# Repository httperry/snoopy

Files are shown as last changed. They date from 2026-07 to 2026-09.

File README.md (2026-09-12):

<picture>
  <source media="(prefers-color-scheme: dark)" srcset="Resources/Icons/Snoopy Exports/Snoopy-macOS-Default-1024@1x.png">
  <source media="(prefers-color-scheme: light)" srcset="Resources/Icons/Snoopy Exports/Snoopy-macOS-Dark-1024@1x.png">
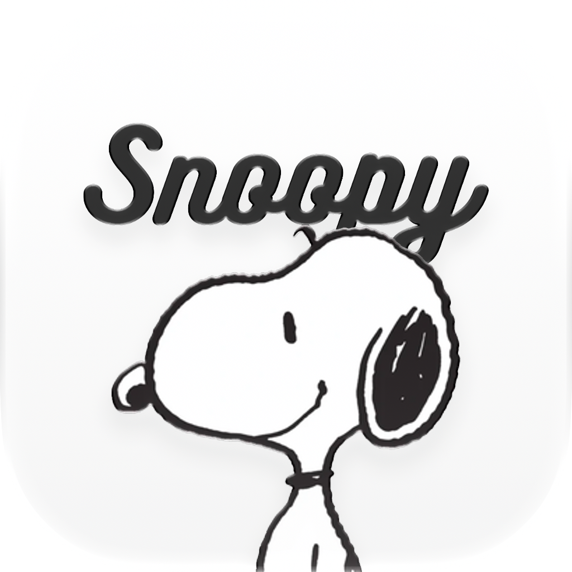
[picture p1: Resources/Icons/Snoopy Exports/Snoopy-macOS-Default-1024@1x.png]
Snoopy Icon
  
</picture>

# Snoopy





**A 3-port Ethernet switch with a built-in monitoring layer, powered by a Raspberry Pi CM4. Sits between your ISP's router and your devices, giving you real visibility and control over your home network — something most stock router software simply doesn't offer**

EasyEDA: [Snoopy](https://u.easyeda.com/join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)
To view on EasyEDA accept the invitation, then go to EasyEDA editor and see the shared project there not on OSWLab

BOM: [BOM.csv](./BOM.csv)

---

**Navigate:** [Schematics](./Schematics/README.md) · [PCB](./PCB/README.md) · [Enclosure](./Enclosure/README.md) · [BOM](./BOM.md) · [Resources](./Resources/README.md)

---

## Overview

Snoopy is a custom PCB that combines a 3-port Gigabit Ethernet switch (Realtek RTL8367S) with a Raspberry Pi CM4 as the system brain. The idea is simple: your ISP's router is a locked-down box, and there's only so much you can do with its stock software. Snoopy plugs into that setup and hands control back to you — packet inspection, traffic monitoring, custom routing rules, whatever you want to run on the CM4

The board handles its own power management, runs the CM4 over a high-density board-to-board connector, and exposes two RJ45 MagJack ports for the switch-side connections. Designed in EasyEDA

For component details, see the [BOM](./BOM.md). For schematics, head to [Schematics](./Schematics/README.md)

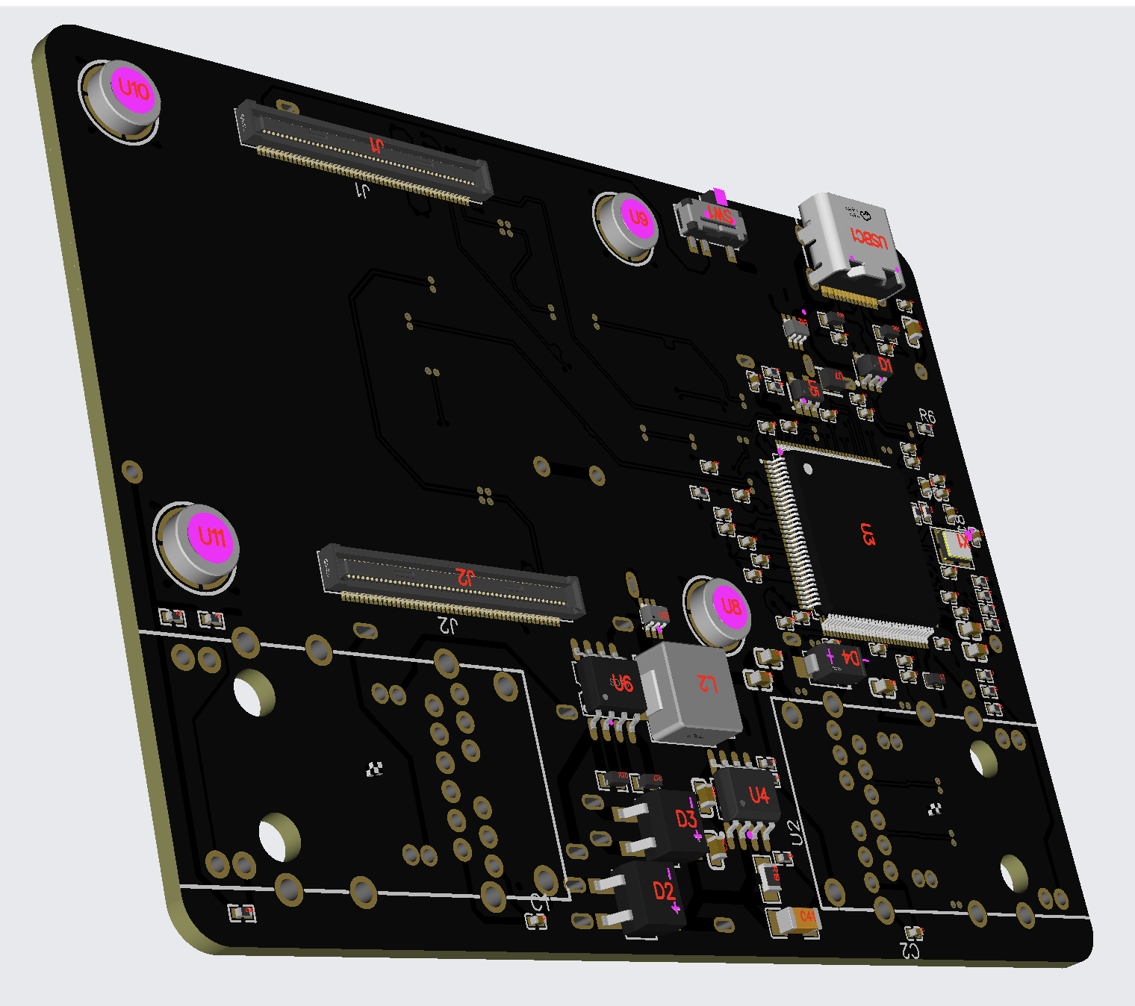
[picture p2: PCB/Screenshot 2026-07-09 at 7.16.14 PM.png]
PCB


---

## Progress

| Module | Status | Schematic |
|---|---|---|
| PWR Management |  | [View](./Schematics/PWR%20Management/README.md) |
| Ethernet Connections |  | [View](./Schematics/Ethernet%20Connections/README.md) |
| CM4 Connections |  | [View](./Schematics/CM4%20Connections/README.md) |
| PCB Layout & Routing |  | [View](./PCB/README.md) |
| Enclosure |  | [View](./Enclosure/README.md) |

---

## License

MIT — see [LICENSE](./LICENSE)

---

Hack Club &nbsp; A [Hack Club](https://hackclub.com) project, built for [Macondo](https://github.com/hackclub/macondo).

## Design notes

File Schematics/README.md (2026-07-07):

[← Back to Root](https://github.com/httperry/snoopy)

# Schematics




EasyEDA schematic sheets for Snoopy, one folder per functional module. Each folder contains the schematic as a PDF, PNG, and SVG export

---

| Module | Status | Directory |
|---|---|---|
| PWR Management |  | [PWR Management](./PWR%20Management/README.md) |
| Ethernet Connections |  | [Ethernet Connections](./Ethernet%20Connections/README.md) |
| CM4 Connections |  | [CM4 Connections](./CM4%20Connections/README.md) |

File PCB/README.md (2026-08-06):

[← Back to Root](https://github.com/httperry/snoopy)

# PCB Layout & Routing




Full board layout and routing for Snoopy — 3-port Ethernet switch with CM4. Gerbers are production-ready and exported for JLCPCB

---

PCB Preview

---

## Exports

| File | Format | Description |
|---|---|---|
| [Gerber_Snoopy_PCB_Snoopy_2026-07-09.zip](./Gerber_Snoopy_PCB_Snoopy_2026-07-09.zip) | ZIP | Gerber files for fabrication |
| [PCB_PCB_Snoopy_2026-08-06.json](./PCB_PCB_Snoopy_2026-08-06.json) | JSON | JSON PCB files |
| [PCB_PCB-Snoopy_2026-07-09.svg](./PCB_PCB-Snoopy_2026-07-09.svg) | SVG | Full board SVG export |
| [PickAndPlace_PCB_Snoopy_2026-07-09.csv](./PickAndPlace_PCB_Snoopy_2026-07-09.csv) | CSV | Pick and place file for assembly |

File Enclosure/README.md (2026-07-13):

[← Back to Root](https://github.com/httperry/snoopy)

# Enclosure




3D-printed enclosure for Snoopy, designed in Fusion 360. Split into a top and bottom shell that sandwich the PCB

---

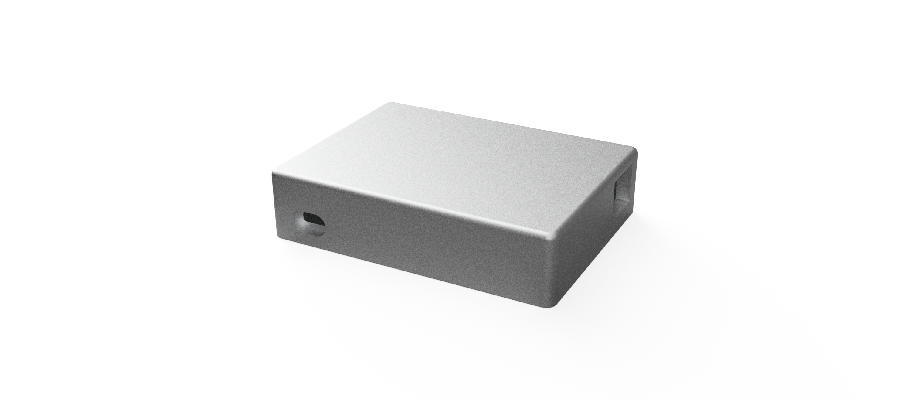
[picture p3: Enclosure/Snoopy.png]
Enclosure


---

## Exports

| File | Format | Description |
|---|---|---|
| [Snoopy.f3d](./Snoopy.f3d) | F3D | Full assembly Fusion 360 source file |
| [Snoopy.step](./Snoopy.step) | STEP | Full assembly STEP export (for slicing / import) |
| [TopShell.f3d](./TopShell.f3d) | F3D | Top shell Fusion 360 source |
| [BottomShell.step](./BottomShell.step) | STEP | Bottom shell STEP export |

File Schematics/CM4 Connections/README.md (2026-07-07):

[← Back to Root](https://github.com/httperry/snoopy)

# CM4 Connections



Covers the interface between the board and the Raspberry Pi CM4. The CM4 connects through two high-density 100-pin DF40C board-to-board connectors (J1, J2), which carry power, USB, PCIe, HDMI, and the RGMII signals that feed into the RTL8367S switch. Also includes the USB-C port for programming and a reset/boot switch

---

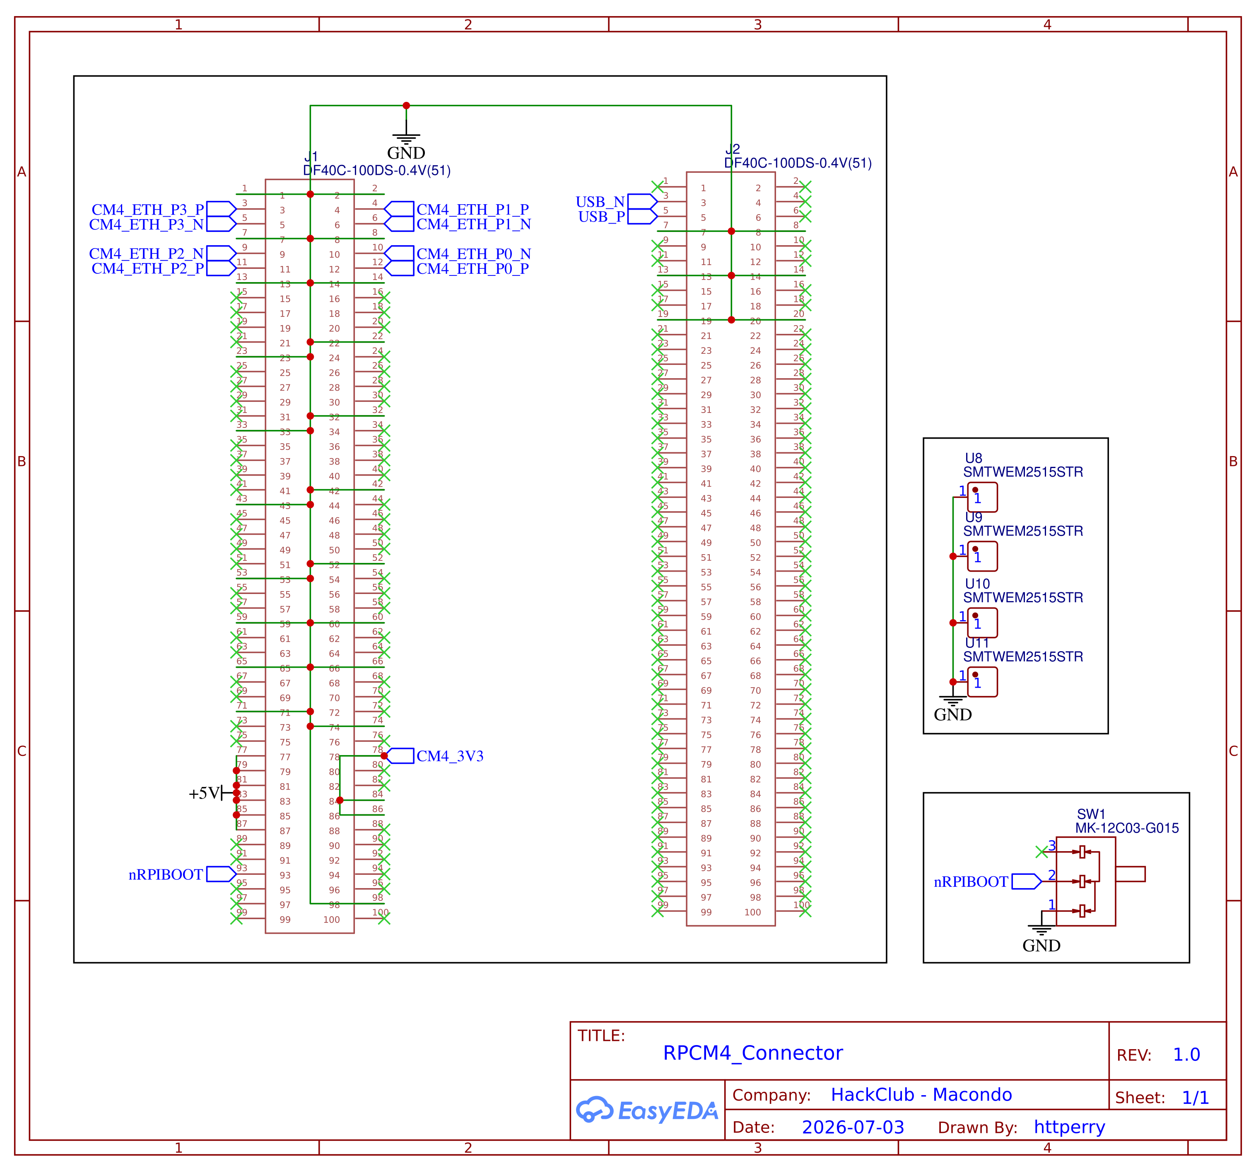
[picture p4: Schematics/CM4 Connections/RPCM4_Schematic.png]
CM4 Connections Schematic


---

## Exports

| File | Format |
|---|---|
| [RPCM4_Schematic.pdf](./RPCM4_Schematic.pdf) | PDF |
| [RPCM4_Schematic.png](./RPCM4_Schematic.png) | PNG |
| [RPCM4_Connector_2026-07-06.svg](./RPCM4_Connector_2026-07-06.svg) | SVG |

---

## Key Components

| Component | Part | Function |
|---|---|---|
| J1, J2 | DF40C-100DS-0.4V(51) | CM4 board-to-board connectors (100-pin, 0.4mm pitch) |
| USBC1 | TYPE-C-31-M-12 | USB-C port for CM4 programming |
| SW1 | MK-12C03-G015 | Power / boot select switch |
| U12, U13 | LM66100DCKR | Ideal diode for power rail protection |
| U7 | FTC201610S2R2MBCA | 2.2µH inductor for CM4 supply filtering |

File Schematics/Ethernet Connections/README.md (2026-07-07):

[← Back to Root](https://github.com/httperry/snoopy)

# Ethernet Connections



The switch fabric and physical layer connections. The RTL8367S acts as the 3-port GbE switch IC, with two ports broken out to integrated MagJack connectors (JT7-1119NL) and the third port connecting internally to the CM4's RGMII interface. Pulse transformers (SMTWEM2515STR) handle the magnetics for each port, and a 25MHz crystal provides the reference clock

---

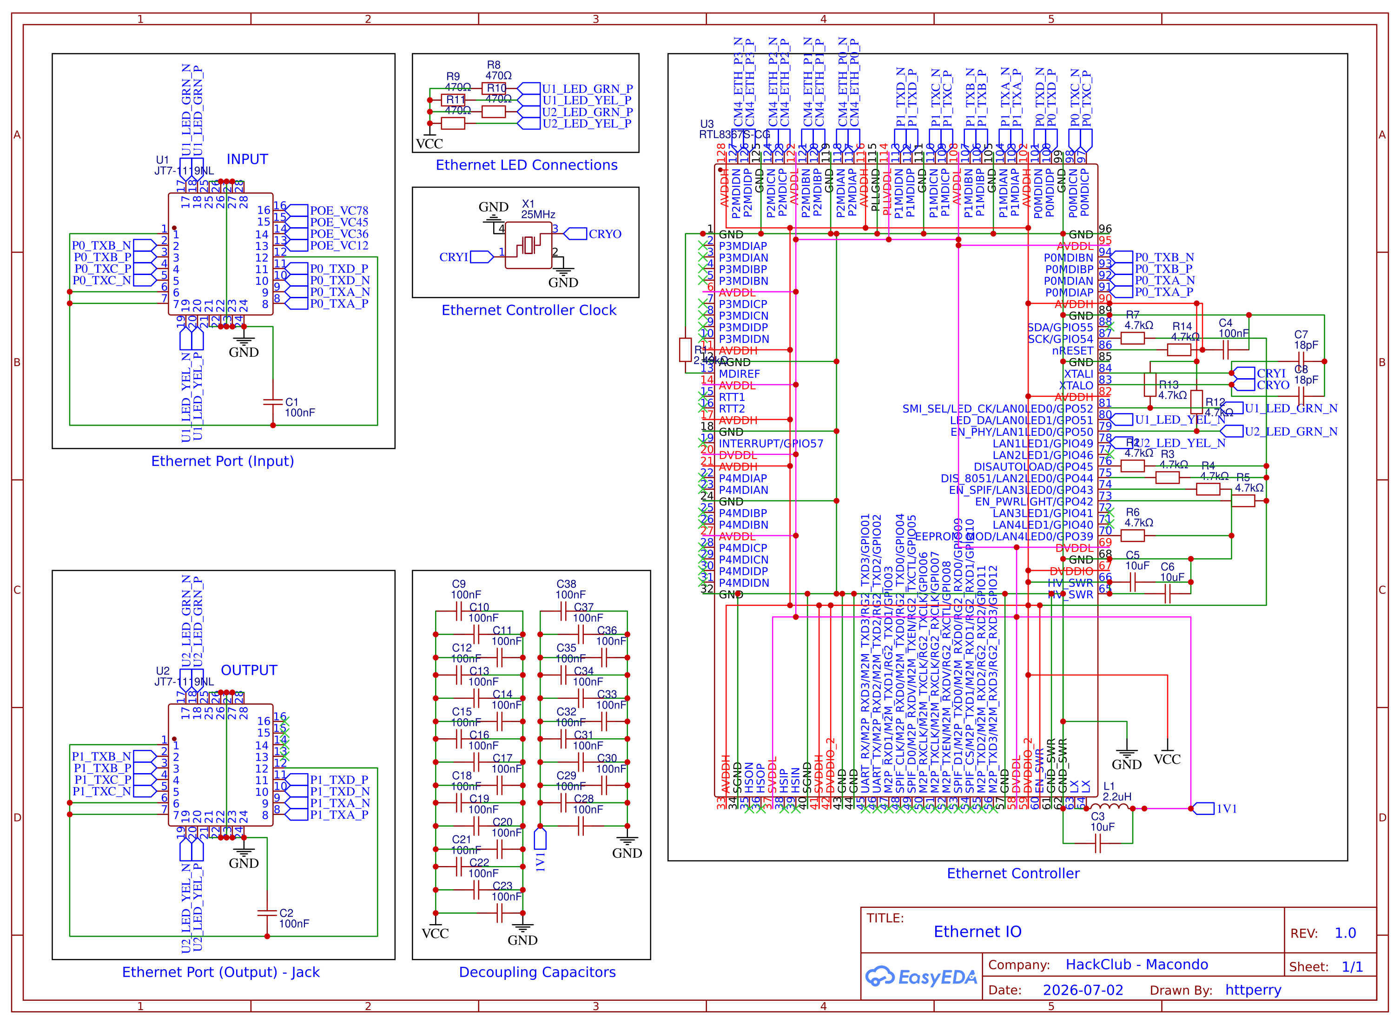
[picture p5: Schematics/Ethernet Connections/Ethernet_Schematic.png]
Ethernet Connections Schematic


---

## Exports

| File | Format |
|---|---|
| [Ethernet_Schematic.pdf](./Ethernet_Schematic.pdf) | PDF |
| [Ethernet_Schematic.png](./Ethernet_Schematic.png) | PNG |
| [Ethernet_IO_2026-07-06.svg](./Ethernet_IO_2026-07-06.svg) | SVG |

---

## Key Components

| Component | Part | Function |
|---|---|---|
| U3 | RTL8367S-CG | 3-port Gigabit Ethernet switch IC |
| U1, U2 | JT7-1119NL | Integrated MagJack (GbE RJ45 with magnetics) |
| U8–U11 | SMTWEM2515STR | Ethernet pulse transformers |
| X1 | TAXM25M4RLBCCT2T | 25MHz reference crystal |
| D1 | USBLC6-2SC6 | ESD protection |

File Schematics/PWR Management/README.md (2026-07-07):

[← Back to Root](https://github.com/httperry/snoopy)

# PWR Management



Handles all power rails on the board. Takes input via USB-C or PoE, steps it down to the voltages needed by the CM4, the RTL8367S switch, and other ICs. Uses two buck converters (TPS54360 and SY8089) alongside a PoE PD controller (TPS2378) and a pair of LM66100 ideal diode controllers for input source arbitration

---

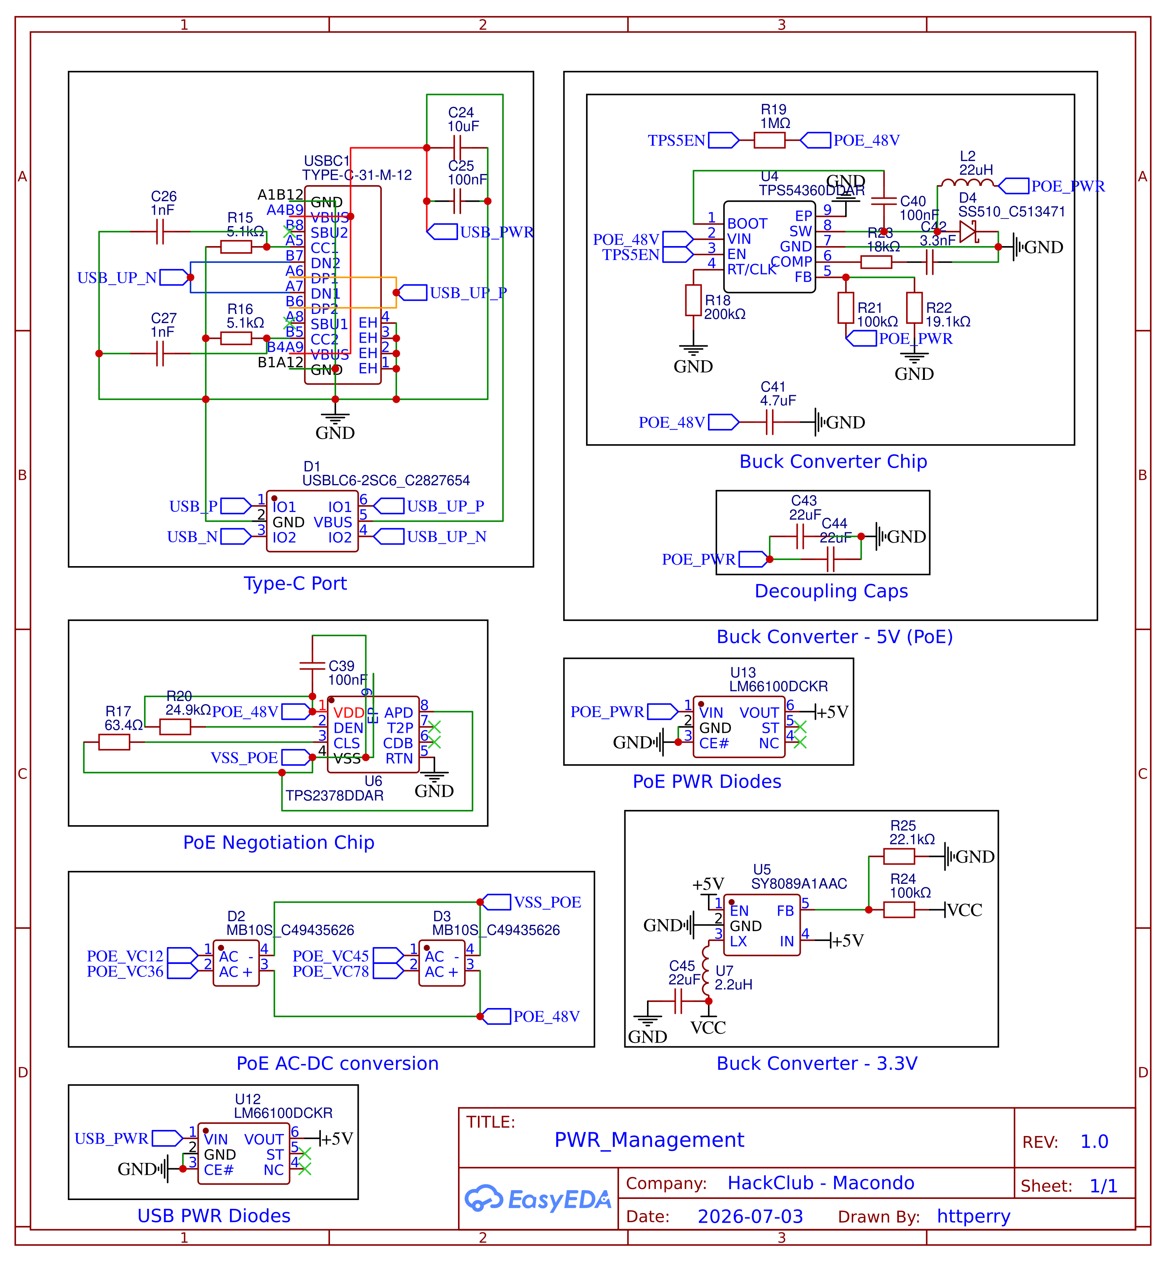
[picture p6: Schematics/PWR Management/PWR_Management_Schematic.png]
PWR Management Schematic


---

## Exports

| File | Format |
|---|---|
| [PWR_Management_Schematic.pdf](./PWR_Management_Schematic.pdf) | PDF |
| [PWR_Management_Schematic.png](./PWR_Management_Schematic.png) | PNG |
| [PWR_Management_2026-07-06.svg](./PWR_Management_2026-07-06.svg) | SVG |

---

## Key Components

| Component | Part | Function |
|---|---|---|
| U4 | TPS54360DDAR | Main 60V/3.5A buck converter |
| U5 | SY8089A1AAC | 3A synchronous buck for CM4 core |
| U6 | TPS2378DDAR | PoE PD controller |
| U12, U13 | LM66100DCKR | Ideal diode / input OR-ing |
| D2, D3 | MB10S | Bridge rectifier for PoE input |
| D4 | SS510 | Schottky protection diode |
| L1 | ZEMS16086S-2R2M | 2.2µH power inductor |
| L2 | YSPI0630A-220M | 22µH power inductor |

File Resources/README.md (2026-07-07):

[← Back to Root](https://github.com/httperry/snoopy)

# Resources

This directory contains static assets used by the project and its documentation

## Structure

```
Resources/
└── Icons/
    └── Snoopy Exports/
        ├── Snoopy-macOS-Default-1024@1x.png    # Default icon (light mode)
        ├── Snoopy-macOS-Dark-1024@1x.png        # Dark background variant
        ├── Snoopy-macOS-ClearDark-1024@1x.png   # Clear dark variant
        ├── Snoopy-macOS-ClearLight-1024@1x.png  # Clear light variant
        ├── Snoopy-macOS-TintedDark-1024@1x.png  # Tinted dark variant
        └── Snoopy-macOS-TintedLight-1024@1x.png # Tinted light variant
```

## Icons

The project icon is exported in multiple variants for use across different backgrounds and contexts. GitHub READMEs use the `<picture>` element to serve the correct variant based on the viewer's system theme — Default for dark mode, Dark for light mode

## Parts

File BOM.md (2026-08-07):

[← Back to Root](https://github.com/httperry/snoopy)

# Bill of Materials

**Snoopy** — 3-Port Ethernet Switch with CM4 Monitoring
Last Updated: 2026-07-09 · REV 1.1

[CSV Format](./BOM/BOM_Snoopy_2026-07-09.csv)

---

## Core Compute

| Component | Source | Qty | Product Link |
|---|---|---|---|
| Raspberry Pi CM4 | Raspberry Pi | 1 | [thingbits.in](https://www.thingbits.in/products/raspberry-pi-compute-module-4) |
| DF40C-100DS-0.4V(51) CM4 Board-to-Board Connector | LCSC | 2 | [lcsc.com](https://www.lcsc.com/product-detail/Board-to-Board-Connectors_HRS_C597931.html) |

---

## Networking

*Source: [Schematics/Ethernet Connections](./Schematics/Ethernet%20Connections/README.md)*

| Component | Source | Qty | Product Link |
|---|---|---|---|
| RTL8367S-CG 3-Port GbE Switch IC | LCSC | 1 | [lcsc.com](https://www.lcsc.com/product-detail/Ethernet-ICs_REALTEK-RTL8367S-CG_C2760849.html) |
| JT7-1119NL Integrated MagJack (GbE RJ45) | LCSC | 2 | [lcsc.com](https://www.lcsc.com/product-detail/Ethernet-Connectors_PULSE-JT7-1119NL_C3178801.html) |
| SMTWEM2515STR Ethernet Pulse Transformer | LCSC | 4 | [lcsc.com](https://www.lcsc.com/product-detail/LAN-Transformers_YIYUAN-SMTWEM2515STR_C5301785.html) |
| TAXM25M4RLBCCT2T 25MHz Crystal | LCSC | 1 | [lcsc.com](https://www.lcsc.com/product-detail/Crystals_YJX-TAXM25M4RLBCCT2T_C164045.html) |

---

## Power Management

*Source: [Schematics/PWR Management](./Schematics/PWR%20Management/README.md)*

| Component | Source | Qty | Product Link |
|---|---|---|---|
| TPS54360DDAR 60V 3.5A Buck Converter | LCSC | 1 | [lcsc.com](https://www.lcsc.com/product-detail/DC-DC-Converters_TI_C44377.html) |
| SY8089A1AAC 3A Synchronous Buck Regulator | LCSC | 1 | [lcsc.com](https://www.lcsc.com/product-detail/DC-DC-Converters_Silergy_C479074.html) |
| TPS2378DDAR PoE PD Controller | LCSC | 1 | [lcsc.com](https://www.lcsc.com/product-detail/Power-Management-ICs_TI_C337500.html) |
| LM66100DCKR Ideal Diode Controller | LCSC | 2 | [lcsc.com](https://www.lcsc.com/product-detail/PMIC-Gate-Drivers_TI_C2869734.html) |
| USBLC6-2SC6 USB ESD Protection | LCSC | 1 | [lcsc.com](https://www.lcsc.com/product-detail/ESD-and-Surge-Protection_TECH-PUBLIC_C2827654.html) |
| MB10S Bridge Rectifier | LCSC | 2 | [lcsc.com](https://www.lcsc.com/product-detail/Rectifier-Diodes_Huixin_C49435626.html) |
| SS510 Schottky Diode | LCSC | 1 | [lcsc.com](https://www.lcsc.com/product-detail/Schottky-Diodes_Slkor_C513471.html) |
| MK-12C03-G015 Power Switch | LCSC | 1 | [lcsc.com](https://www.lcsc.com/product-detail/Slide-Switches_G-Switch_C2890358.html) |
| TYPE-C-31-M-12 USB-C Connector | LCSC | 1 | [lcsc.com](https://www.lcsc.com/product-detail/USB-Connectors_C165948.html) |
| ZEMS16086S-2R2M 2.2µH Inductor | LCSC | 1 | [lcsc.com](https://www.lcsc.com/product-detail/Inductors_ZE_C48945029.html) |
| YSPI0630A-220M 22µH Inductor | LCSC | 1 | [lcsc.com](https://www.lcsc.com/product-detail/Inductors_YJYCOIN_C497873.html) |
| FTC201610S2R2MBCA 2.2µH Inductor | LCSC | 1 | [lcsc.com](https://www.lcsc.com/product-detail/Inductors_cjiang_C58323440.html) |

---

## Passives — Capacitors

| Value | Footprint | Qty | Manufacturer P/N | Source | LCSC # |
|---|---|---|---|---|---|
| 100nF | C0402 | 29 | AC0402KRX7R9BB104 | YAGEO | C288326 |
| 10µF | C0603 | 4 | HGC0603R5106M250NTHJ | Chinocera | C7472961 |
| 18pF | C0402 | 2 | GRM1555C1H180JA01D | muRata | C33149 |
| 100nF | C0402 | 1 | CC0402KRX5R8BB104 | YAGEO | C106256 |
| 1nF | C0402 | 2 | CC0402KRX7R8BB102 | YAGEO | C541372 |
| 100nF | C0603 | 2 | GCJ188R72A104KA01D | muRata | C161117 |
| 4.7µF | C1206 | 1 | GRM31CC72A475KE11L | muRata | C237304 |
| 3.3nF | C0402 | 1 | CC0402KRX7R9BB332 | YAGEO | C107028 |
| 22µF | C0603 | 2 | CL10A226MP8NUNE | SAMSUNG | C86295 |
| 22µF | C0402 | 1 | HGC0402R52226M100NTEJ | Chinocera | C22367823 |

---

## Passives — Resistors

| Value | Footprint | Qty | Manufacturer P/N | Source | LCSC # |
|---|---|---|---|---|---|
| 2.49kΩ | R0402 | 1 | FRC0402F2491TS | FOJAN | C2933083 |
| 4.7kΩ | R0402 | 9 | CRCW04024K70FKED | VISHAY | C482193 |
| 470Ω | R0402 | 4 | FRC0402F4700TS | FOJAN | C2909361 |
| 5.1kΩ | R0603 | 2 | RMC06035.1K5%N | Tyohm | C269696 |
| 63.4Ω | R0603 | 1 | PTFR0603B63R4P9 | RESI | C47115900 |
| 200kΩ | R0402 | 1 | ARG02BTC2003 | Viking | C2984414 |
| 1MΩ | R0805 | 1 | AR05BTC1004 | Viking | C374666 |
| 24.9kΩ | R0603 | 1 | PTFR0603B24K9N9 | RESI | C2692729 |
| 100kΩ | R0402 | 2 | RT0402BRD07100KL | YAGEO | C852472 |
| 19.1kΩ | R0402 | 1 | FRC0402F1912TS | FOJAN | C2998158 |
| 18kΩ | R0402 | 1 | AECR0402F18K0K9 | RESI | C352468 |
| 22.1kΩ | R0402 | 1 | CRCW040222K1FKED | VISHAY | C844504 |

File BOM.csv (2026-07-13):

ID | Name | Designator | Footprint | Quantity | Manufacturer Part | Manufacturer | Supplier | Supplier Part | Price | Pins | 3DModel | Contributor | JLCPCB Part Class | link
1 | 100nF | C1,C2,C4,C9,C10,C11,C12,C13,C14,C15,C16,C17,C18,C19,C20,C21,C22,C23,C28,C29,C30,C31,C32,C33,C34,C35,C36,C37,C38 | C0402 | 29 | AC0402KRX7R9BB104 | YAGEO(国巨) | LCSC | C2888326 | 0.017 | 2 | C0402_L1.0-W0.5-H0.5 | LCSC | Extended Part | https://item.szlcsc.com/15869.html
2 | 18pF | C7,C8 | C0402 | 2 | GRM1555C1H180JA01D | muRata(村田) | LCSC | C33149 | 0.006 | 2 | C0402_L1.0-W0.5-H0.5 | lcsc | Extended Part | https://item.szlcsc.com/15869.html
3 | 100nF | C25 | C0402 | 1 | CC0402KRX5R8BB104 | YAGEO(国巨) | LCSC | C106256 | 0.011 | 2 | C0402_L1.0-W0.5-H0.5 | lcsc | Extended Part | https://item.szlcsc.com/15869.html
4 | 1nF | C26,C27 | C0402 | 2 | CC0402KRX7R8BB102 | YAGEO(国巨) | LCSC | C541372 | 0.002 | 2 | C0402_L1.0-W0.5-H0.5 | LCSC | Extended Part | https://item.szlcsc.com/15869.html
5 | 3.3nF | C42 | C0402 | 1 | CC0402KRX7R9BB332 | YAGEO(国巨) | LCSC | C107028 | 0.002 | 2 | C0402_L1.0-W0.5-H0.5 | lcsc | Extended Part | https://item.szlcsc.com/15869.html
6 | 22uF | C45 | C0402 | 1 | HGC0402R5226M100NTEJ | Chinocera(华瓷) | LCSC | C22367823 | 0.296 | 2 | C0402_L1.0-W0.5-H0.5 | lcsc | Extended Part | https://item.szlcsc.com/15869.html
7 | 10uF | C3,C5,C6,C24 | C0603 | 4 | HGC0603R5106M250NTHJ | Chinocera(华瓷) | LCSC | C7472961 | 0.098 | 2 | C0603_L1.6-W0.8-H0.8 | lcsc | Extended Part | https://item.szlcsc.com/362304.html
8 | 100nF | C39,C40 | C0603 | 2 | GCJ188R72A104KA01D | muRata(村田) | LCSC | C161117 | 0.044 | 2 | C0603_L1.6-W0.8-H0.8 | LCSC | Extended Part | https://item.szlcsc.com/362304.html
9 | 22uF | C43,C44 | C0603 | 2 | CL10A226MP8NUNE | SAMSUNG(三星) | LCSC | C86295 | 0.153 | 2 | C0603_L1.6-W0.8-H0.8 | lcsc | Extended Part | https://lcsc.com/eda_search?q=C86295&%26type=1&ref=editor
10 | 4.7uF | C41 | C1206 | 1 | GRM31CC72A475KE11L | muRata(村田) | LCSC | C237304 | 0.606 | 2 | C1206_L3.2-W1.6-H1.3 | LCSC | Extended Part | https://item.szlcsc.com/89171.html
11 | USBLC6-2SC6_C2827654 | D1 | SOT-23-6_L2.9-W1.6-P0.95-LS2.8-BL | 1 | USBLC6-2SC6 | TECH PUBLIC(台舟) | LCSC | C2827654 | 0.045 | 6 | SOT-23-6_L2.9-W1.6-H1.5-LS2.8-P0.95 | LCSC | Extended Part | https://item.szlcsc.com/169042.html
12 | MB10S_C49435626 | D2,D3 | MBS_L4.7-W4.0-P2.50-LS7.0-TL | 2 | MB10S | Huixin(慧芯) | LCSC | C49435626 | 0.104 | 4 | MBS_L4.7-W4.0-H2.5-LS7.0 | lcsc | Extended Part | https://item.szlcsc.com/335287.html
13 | SS510_C513471 | D4 | SMA_L4.3-W2.6-LS5.0-RD | 1 | SS510 | Slkor(萨科微) | LCSC | C513471 | 0.037 | 2 | SMA_L4.3-W2.6-LS5.0-RD | LCSC | Extended Part | https://lcsc.com/eda_search?q=C513471&%26type=1&ref=editor
14 | 2.2uH | L1 | IND-SMD_L1.6-W0.8_FTC160865S2R2MBCA | 1 | ZEMS160865-2R2M | ZE(增益) | LCSC | C48945029 | 0.106 | 2 | IND-SMD_L1.6-W0.8_FTC160865S2R2MBCA | lcsc | Extended Part | https://atta.szlcsc.com/upload/public/pdf/source/20250425/4F0E02747B4B2E4723AF93BE4B85866C.pdf
15 | 22uH | L2 | IND-SMD_L7.1-W6.6 | 1 | YSPI0630A-220M | YJYCOIN(益嘉源) | LCSC | C497873 | 0.131 | 2 | IND-SMD_L6.6-W7.1-H3.0 | LCSC | Extended Part | https://item.szlcsc.com/421431.html
16 | 2.49kΩ | R1 | R0402 | 1 | FRC0402F2491TS | FOJAN(富捷) | LCSC | C2933083 | 0.002 | 2 | R0402_L1.0-W0.5-H0.4 | lcsc | Extended Part | https://item.szlcsc.com/323315.html
17 | 4.7kΩ | R2,R3,R4,R5,R6,R7,R12,R13,R14 | R0402 | 9 | CRCW04024K70FKED | VISHAY(威世) | LCSC | C482193 | 0.004 | 2 | R0402_L1.0-W0.5-H0.4 | LCSC | Extended Part | https://item.szlcsc.com/323315.html
18 | 470Ω | R8,R9,R10,R11 | R0402 | 4 | FRC0402F4700TS | FOJAN(富捷) | LCSC | C2909361 | 0.002 | 2 | R0402_L1.0-W0.5-H0.4 | lcsc | Extended Part | https://item.szlcsc.com/323315.html
19 | 200kΩ | R18 | R0402 | 1 | ARG02BTC2003 | Viking(光颉) | LCSC | C2984414 | 0.022 | 2 | R0402_L1.0-W0.5-H0.4 | lcsc | Extended Part | https://item.szlcsc.com/323315.html
20 | 100kΩ | R21,R24 | R0402 | 2 | RT0402BRD07100KL | YAGEO(国巨) | LCSC | C852472 | 0.024 | 2 | R0402_L1.0-W0.5-H0.4 | lcsc | Extended Part | https://item.szlcsc.com/323315.html
21 | 19.1kΩ | R22 | R0402 | 1 | FRC0402F1912TS | FOJAN(富捷) | LCSC | C2998158 | 0.002 | 2 | R0402_L1.0-W0.5-H0.4 | lcsc | Extended Part | https://item.szlcsc.com/323315.html
22 | 18kΩ | R23 | R0402 | 1 | AECR0402F18K0K9 | RESI(开步睿思) | LCSC | C352468 | 0.006 | 2 | R0402_L1.0-W0.5-H0.4 | LCSC | Extended Part | https://item.szlcsc.com/323315.html
23 | 22.1kΩ | R25 | R0402 | 1 | CRCW040222K1FKED | VISHAY(威世) | LCSC | C844504 | 0.004 | 2 | R0402_L1.0-W0.5-H0.4 | lcsc | Extended Part | https://item.szlcsc.com/323315.html
24 | 5.1kΩ | R15,R16 | R0603 | 2 | RMC06035.1K5%N | Tyohm(幸亚电阻) | LCSC | C269696 | 0.003 | 2 | R0603 | LCSC | Extended Part | https://www.mouser.in/datasheet/2/447/PYu_RT_1_to_0_01_RoHS_L_11-1669912.pdf
25 | 63.4Ω | R17 | R0603 | 1 | PTFR0603B63R4P9 | RESI(开步睿思) | LCSC | C47115900 | 0.379 | 2 | R0603 | lcsc | Extended Part | https://www.mouser.in/datasheet/2/447/PYu_RT_1_to_0_01_RoHS_L_11-1669912.pdf
26 | 24.9kΩ | R20 | R0603 | 1 | PTFR0603B24K9N9 | RESI(开步睿思) | LCSC | C2692729 | 0.174 | 2 | R0603 | LCSC | Extended Part | https://www.mouser.in/datasheet/2/447/PYu_RT_1_to_0_01_RoHS_L_11-1669912.pdf
27 | 1MΩ | R19 | R0805 | 1 | AR05BTC1004 | Viking(光颉) | LCSC | C374666 | 0.042 | 2 | R0805_L2.0-W1.3-H0.6 | LCSC | Extended Part | https://item.szlcsc.com/142685.html
28 | MK-12C03-G015 | SW1 | SW-SMD_MK-12C03-G015 | 1 | MK-12C03-G015 | G-Switch(品赞) | LCSC | C2890358 | 0.07 | 3 | SW-SMD_MK-12C03-G015 | lcsc | Extended Part | https://atta.szlcsc.com/upload/public/pdf/source/20210903/D741BE8374CE854DD630D54FFF9BD91E.pdf
29 | JT7-1119NL | U1,U2 | CONN-TH_JT7-1119NL | 2 | JT7-1119NL | PULSE(普思) | LCSC | C3178801 | 7.003 | 28 | hr911196ae | lcsc | Extended Part | https://atta.szlcsc.com/upload/public/pdf/source/20240129/D0D60C6B0E5E7F062628E50EABBC7A66.pdf
30 | RTL8367S-CG | U3 | LQFP-128_L14.0-W14.0-P0.40-LS16.0-BL | 1 | RTL8367S-CG | REALTEK(瑞昱) | LCSC | C2760849 | 2.978 | 128 | LQFP-128_L14.0-W14.0-H1.6-P0.40-LS16.0-BL | LCSC | Extended Part | https://item.szlcsc.com/194336.html
31 | TPS54360DDAR | U4 | SOIC-8_L5.0-W4.0-P1.27-LS6.0-BL-EP2.0 | 1 | TPS54360DDAR | TI(德州仪器) | LCSC | C44377 | 0.824 | 9 | SOIC-8_L5.0-W4.0-P1.27-LS6.0-BL-EP2.0 | lcsc | Extended Part | https://item.szlcsc.com/305240.html
32 | SY8089A1AAC | U5 | TSOT-23-5_L2.9-W1.6-P0.95-LS2.8-BR | 1 | SY8089A1AAC | Silergy(矽力杰) | LCSC | C479074 | 0.09 | 5 | TSOT-23-5_L2.9-W1.6-H1.00-LS2.8-P0.95 | LCSC | Extended Part | https://item.szlcsc.com/233411.html
33 | TPS2378DDAR | U6 | SO-8_L4.9-W3.9-P1.27-LS6.0-BL-EP | 1 | TPS2378DDAR | TI(德州仪器) | LCSC | C337500 | 1.237 | 9 | SO-8_L4.9-W3.9-H1.5-LS5.9-P1.27 | LCSC | Extended Part | https://lcsc.com/eda_search?q=C337500&%26type=1&ref=editor
34 | 2.2uH | U7 | IND-SMD_L2.0-W1.6-B | 1 | FTC201610S2R2MBCA | cjiang(长江微电) | LCSC | C5832344 | 0.098 | 2 | IND-SMD_L2.0-W1.6-B | lcsc | Extended Part | https://atta.szlcsc.com/upload/public/pdf/source/20210916/0AAB954FC144BC5BBB2A375AA4447B0B.pdf
35 | SMTWEM2515STR | U8,U9,U10,U11 | SMD_BD5.0-D3.5 | 4 | SMTWEM2515STR | YIYUAN(怡远) | LCSC | C5301785 | 0.068 | 4 | SMD_BD5.0-D3.5 | lcsc | Extended Part | https://atta.szlcsc.com/upload/public/pdf/source/20220525/68D6197F4103C41ADE045118815ED356.pdf
36 | LM66100DCKR | U12,U13 | SC-70-6_L2.0-W1.3-P0.65-LS2.1-BL | 2 | LM66100DCKR | TI(德州仪器) | LCSC | C2869734 | 0.269 | 6 | SC-70-6_L2.0-W1.3-P0.65-LS2.1-BL | LCSC | Extended Part | https://cn.bing.com/search?q=datasheet： LM66100DCKT
37 | TYPE-C-31-M-12 | USBC1 | USB-C_SMD-TYPE-C-31-M-12_1 | 1 | TYPE-C-31-M-12 | 韩国韩荣 | LCSC | C165948 | 0.186 | 16 | USB-C_SMD-TYPE-C-31-M-12_1 | LCSC | Extended Part | https://item.szlcsc.com/datasheet/TYPE-C-31-M-12/177331.html
38 | 25MHz | X1 | CRYSTAL-SMD_4P-L3.2-W2.5-BL-1 | 1 | TAXM25M4RLBCCT2T | YJX(雅晶鑫) | LCSC | C164045 | 0.078 | 4 | CRYSTAL-SMD_4P-L3.2-W2.5-BL-1 | LCSC | Extended Part | https://atta.szlcsc.com/upload/public/pdf/source/20180725/C251604_B37BF3660E3A081576A39813BCE4D878.pdf
39 | DF40C-100DS-0.4V(51) | J1,J2 | HRS_DF40C-100DS-0.4V(51) | 2 | DF40C-100DS-0.4V(51) | HRS(广濑) |  | C597931 | 1.069 | 100 | CONN-SMD_DF40C-100DS-0.4V-51 | Dieter Hamer

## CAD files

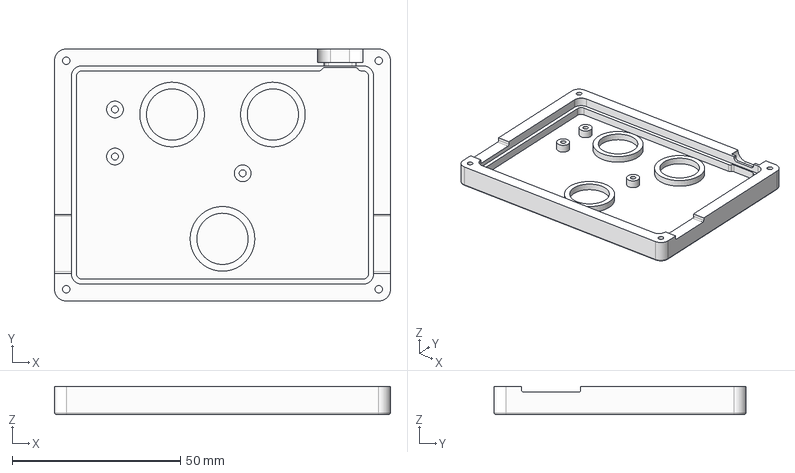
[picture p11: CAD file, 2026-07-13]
Enclosure/BottomShell.step
100.0 x 75.0 x 8.35 mm

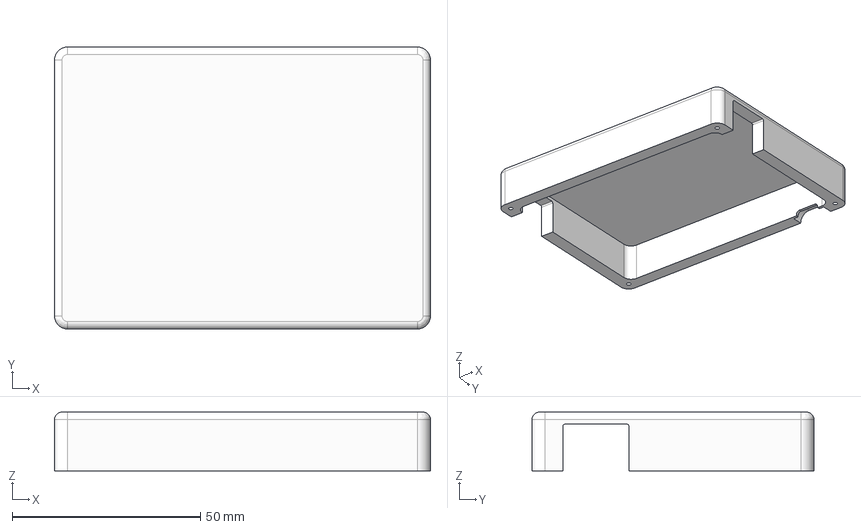
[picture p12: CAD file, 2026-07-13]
Enclosure/TopShell.step
100.0 x 75.0 x 15.6 mm

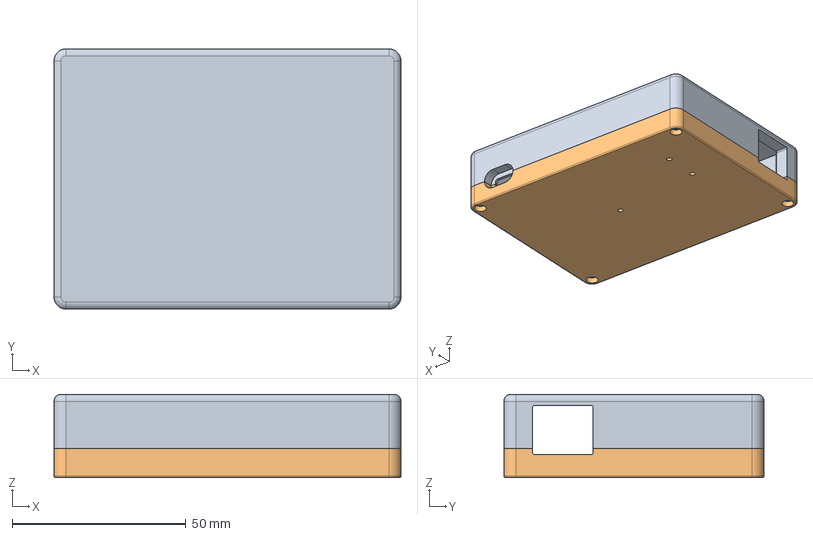
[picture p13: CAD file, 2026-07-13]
Enclosure/Snoopy.step
100.0 x 75.0 x 24.0 mm

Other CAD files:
Enclosure/Snoopy.dxf
Enclosure/Snoopy.f3d

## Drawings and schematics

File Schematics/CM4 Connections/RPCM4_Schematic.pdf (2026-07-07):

A | A

1

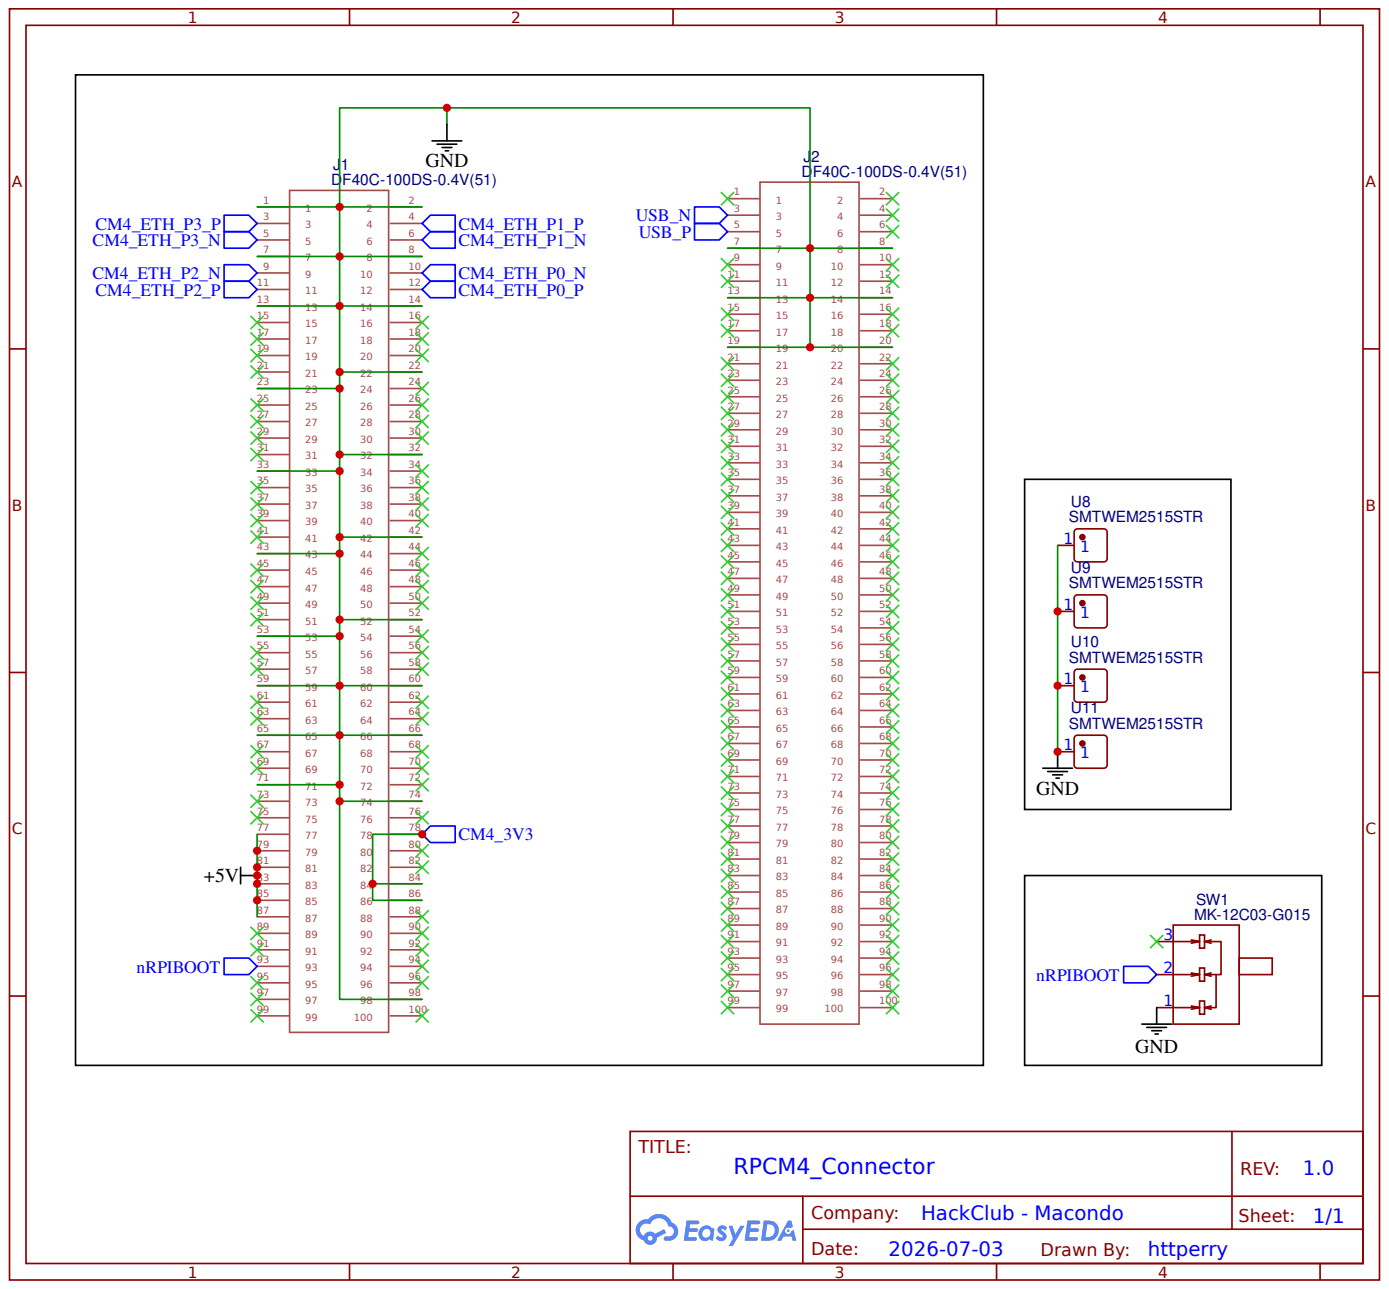
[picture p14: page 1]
TITLE:; RPCM4_Connector; REV: 1.0; Date:; Sheet: 1/1; SMTWEM2515STR; GND; nRPIBOOT; CM4_ETH_P3_P; CM4_ETH_P1_P; CM4_ETH_P3_N; CM4_ETH_P1_N; CM4_ETH_P2_N CM4_ETH_P2_P; CM4_ETH_P0_N CM4_ETH_P0_P; USB_N USB_P

Company: HackClub - Macondo

Drawn By: httperry

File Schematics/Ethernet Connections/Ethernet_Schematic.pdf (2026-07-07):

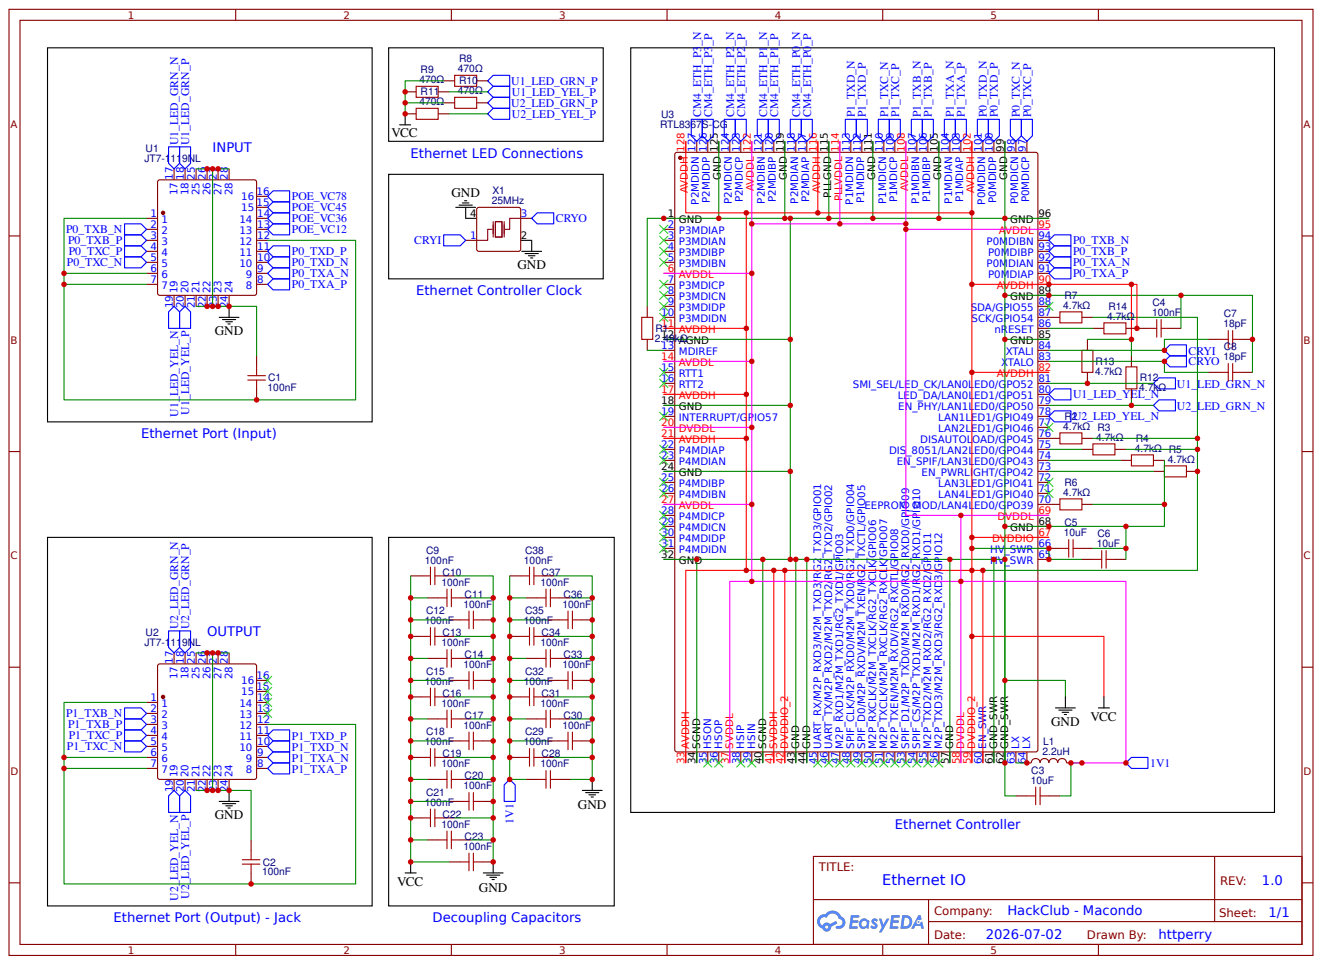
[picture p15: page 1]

HV_SWR 65 HV_SWR 66 DVDDIO 67 GND 68 DVDDL 69 EEPROM_MOD/LAN4LED0/GPO39 70 LAN4LED1/GPIO40 71 LAN3LED1/GPIO41 72 EN_PWRLIGHT/GPO42 73 EN_SPIF/LAN3LED0/GPO43 74 DIS_8051/LAN2LED0/GPO44 75 DISAUTOLOAD/GPO45 76 LAN2LED1/GPIO46 77 LAN1LED1/GPIO49 78 EN_PHY/LAN1LED0/GPO50 79 LED_DA/LAN0LED1/GPO51 80 SMI_SEL/LED_CK/LAN0LED0/GPO52 81 AVDDH 82 XTALO 83 XTALI 84 GND 85 nRESET 86 SCK/GPIO54 87 SDA/GPIO55 88 GND 89 AVDDH 90 P0MDIAP 91 P0MDIAN 92 P0MDIBP 93 P0MDIBN 94 AVDDL 95 GND 96 P0MDICP 97 P0MDICN ⁹⁸ GND ⁹⁹ P0MDIDP 100 P0MDIDN ¹⁰¹ AVDDH ¹⁰² P1MDIAP 103 P1MDIAN ¹⁰⁴ GND ¹⁰⁵ P1MDIBP 106 P1MDIBN ¹⁰⁷ AVDDL 108 P1MDICP 109 P1MDICN ¹¹⁰ GND ¹¹¹ P1MDIDP 112

Ethernet Port (Output) - Jack

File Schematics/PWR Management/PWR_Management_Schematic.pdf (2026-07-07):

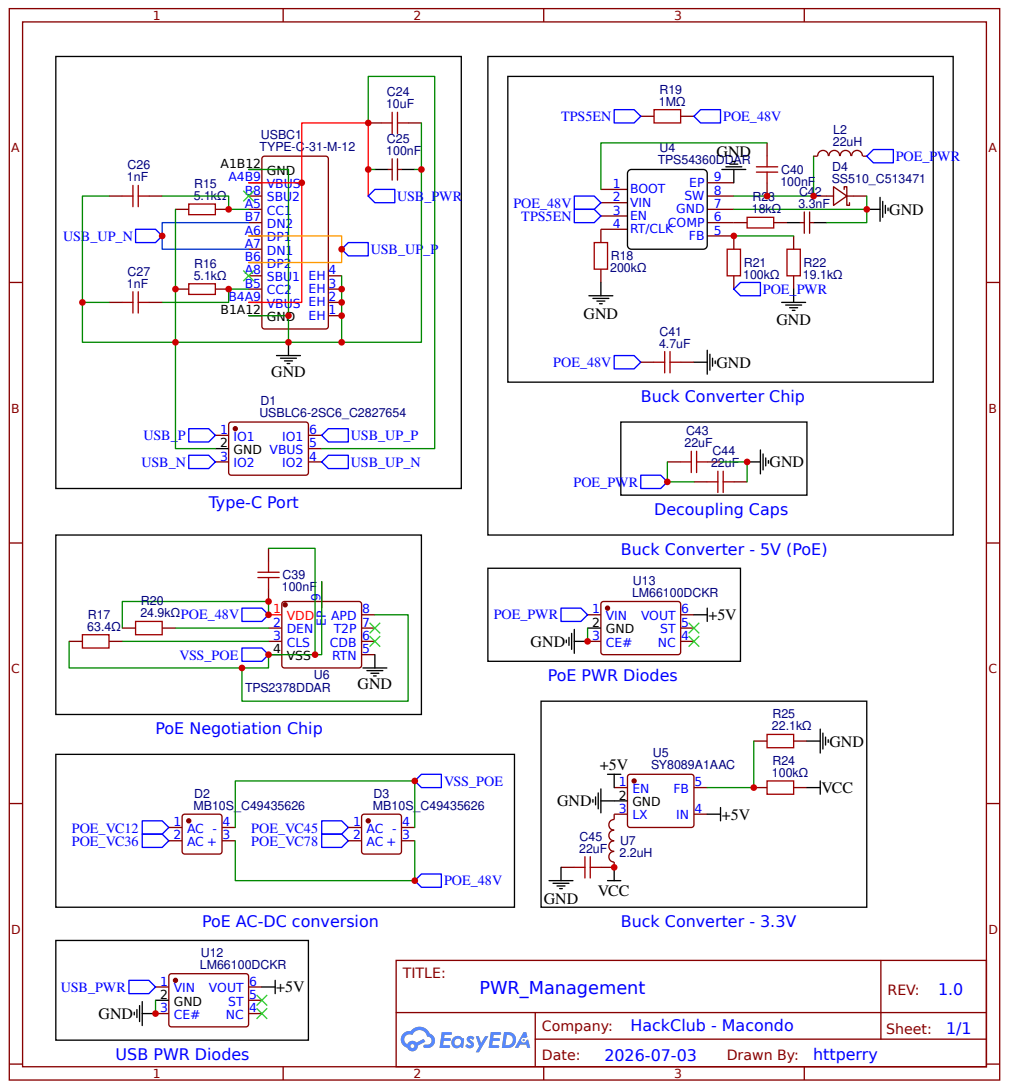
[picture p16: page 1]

Decoupling Caps Type-C Port

PoE AC-DC conversion

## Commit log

2026-07-07 Update ReadMe to reflect PCB Development Status
2026-07-12 Add PCB folder README and update root navigation
2026-07-13 Add Enclosure README, mark project complete
    [BOM_Snoopy_2026-07-06.csv, BOM_Snoopy_2026-07-09.csv, BottomShell.step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]
2026-07-13 Update PCB File & Update BOM
    [PickAndPlace_PCB_Snoopy_2026-07-09.csv, PickAndPlace_PCB_Snoopy_2026-07-13.csv]
2026-07-13 Add rendered image of enclosure
2026-07-13 Add TopShell.step file missed out in previous push
    [TopShell.step]
2026-07-13 Update 3D files
    [BottomShell.step, Snoopy.dxf, TopShell.f3d]
2026-08-06 Add PCB Files - JSON format
2026-08-06 Schematic File for EasyEDA added
2026-08-07 Add CSV format link to BOM for Snoopy
    Updated BOM to include CSV format link for Snoopy.
2026-08-07 update root directory with BOM.csv
    [BOM_Snoopy_2026-07-09.csv]
2026-08-07 Update root directory with new BOM file
    [BOM.csv]
